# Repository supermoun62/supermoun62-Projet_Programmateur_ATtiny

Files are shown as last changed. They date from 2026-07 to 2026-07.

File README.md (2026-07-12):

Programmateur ATtiny 24/44/84 - 25/45/85 - 2313/4313 avec un Arduino Nano.
Vous pouvez récupérer le plan, tuo, liste matériel, fichiers Gerber.

https://github.com/supermoun62/supermoun62-Projet_Programmateur_ATtiny/blob/main/Github_Projet_Programmateur_ATtiny_V3_Images/Projet_Programmateur_ATtiny_V3_PCB.png

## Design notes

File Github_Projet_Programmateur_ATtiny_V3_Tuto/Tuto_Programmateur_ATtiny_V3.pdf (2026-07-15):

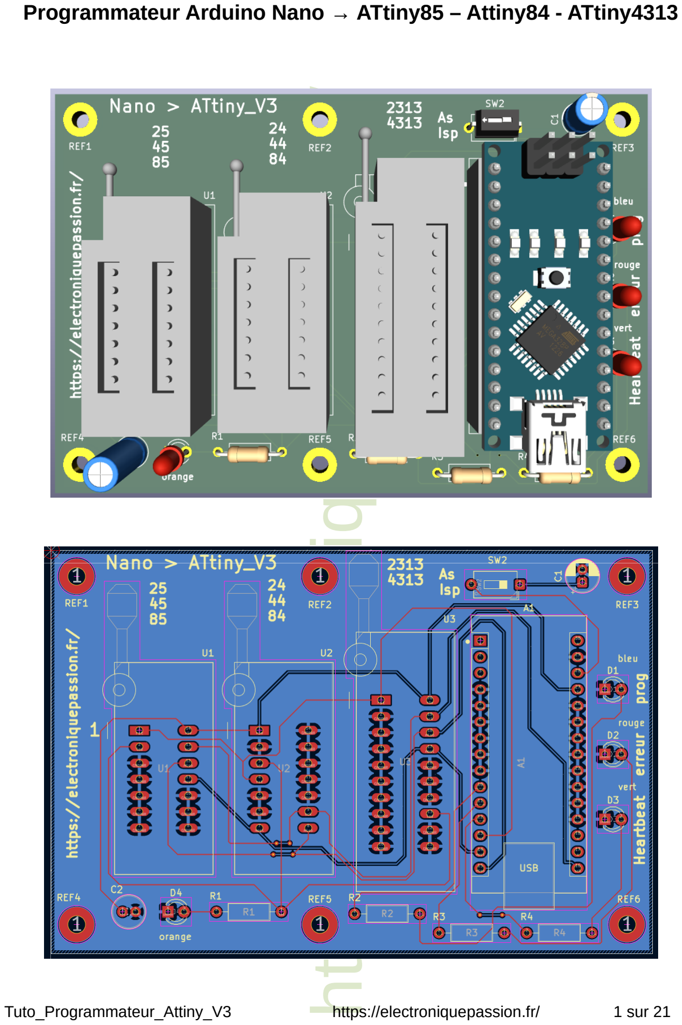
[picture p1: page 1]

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
Tuto_Programmateur_Attiny_V3 | https://electroniquepassion.fr/ | 1 sur 21

Programmateur Arduino Nano → ATtiny85 – Attiny84 - ATtiny4313

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
Tuto_Programmateur_Attiny_V3 | https://electroniquepassion.fr/ | 2 sur 21

Installation d’un Attiny 45, 85

Exemple : un Attiny 85
Insérez l’ATtiny sur le support zif. correspondant.
Pour le zif du 85, je vous conseille de coller un cache sur l’ensemble des pins non utilisées.
( Repérage des pins du zif : 5, 6, 7, 8, 9, 10 )

Informations pour récupérer le dossier Gerber, plans, liste matériel, STL
| à la fin du Tuto

Pour souder le Dip-Switch, ne pas oublier de le mettre dans le bon sens.

Contact fermé vers inscription AsIsp.

### Ce tuto a été réalisé avec un ArduinoIDE V 2.3.10

### Concernant les paramètres de la carte 2313 ou 4313, je n’ai

pas trouvé d’informations sur internet.

Ne pas oublier de mettre en paramètre clock interne.

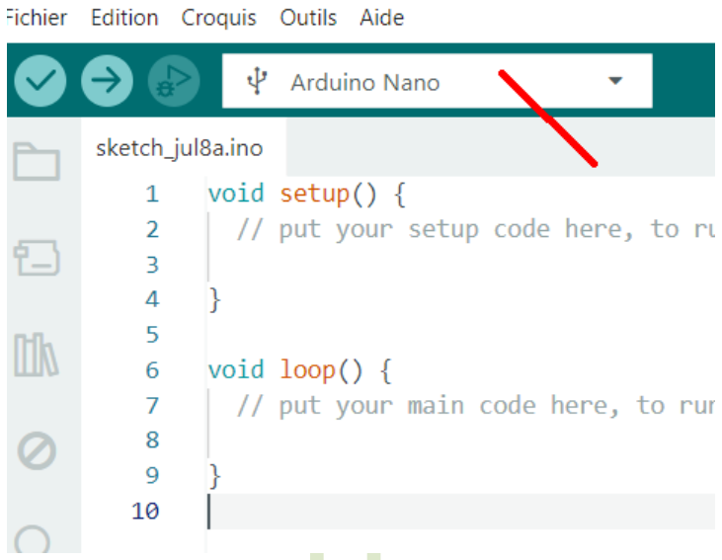
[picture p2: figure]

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
Préparation de l’Arduino Nano en module de programmation.

Arduino Nano

Choix du processeur !!!

Tuto_Programmateur_Attiny_V3 | https://electroniquepassion.fr/ | 3 sur 21

Positionner le Dip-Switch sur la droite afin d’avoir la capacité de 10uf non connectée.
Ensuite connectez le port USB

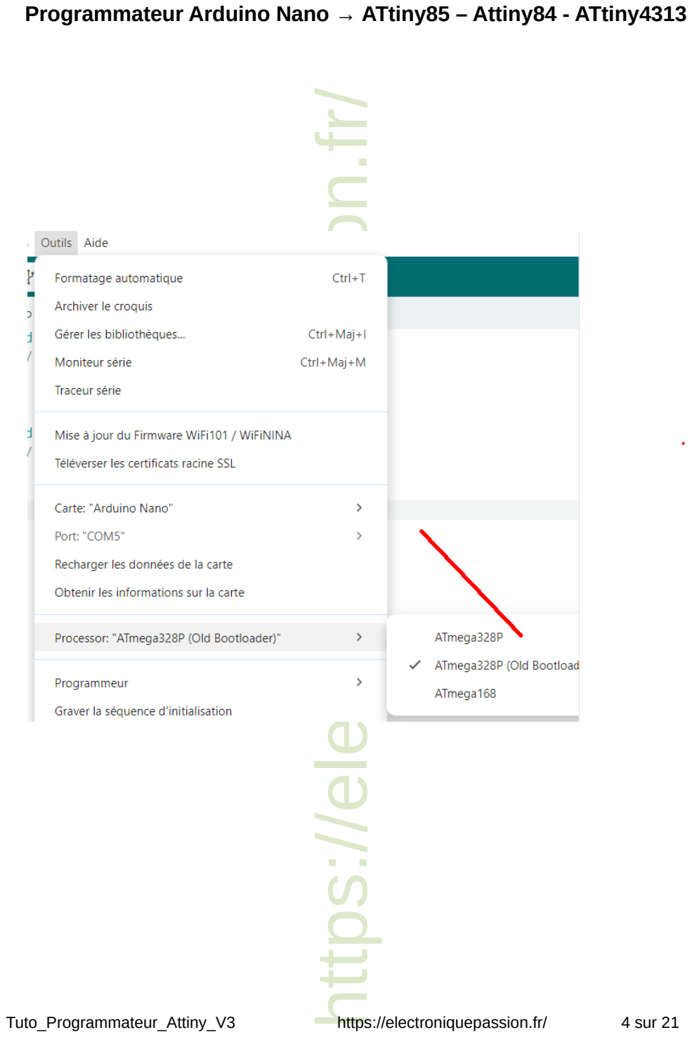
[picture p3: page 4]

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
Tuto_Programmateur_Attiny_V3 | https://electroniquepassion.fr/ | 4 sur 21

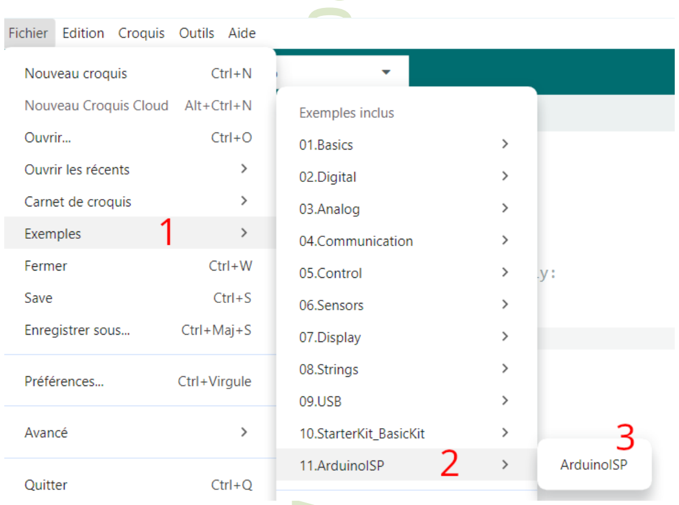
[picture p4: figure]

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
Ensuite ouvrir le croquis Arduino ISP de: Randall Bohn (https://github.com/rsbohn/arduinoisp)

Trouver le croquis : Exemples \ ArduinoISP

Téléverser le programme dans le Nano.

Vérifier l’absence de message de défaut.

A partir de ce moment la Nano est devenue programmateur d’ATtiny.

Tuto_Programmateur_Attiny_V3 | https://electroniquepassion.fr/ | 5 sur 21

Enlever le port USB, basculer le Dip-Switch sur la gauche afin de connecter la capacité de 10uf .
A partir de ce moment, ne plus toucher au Dip-Switch

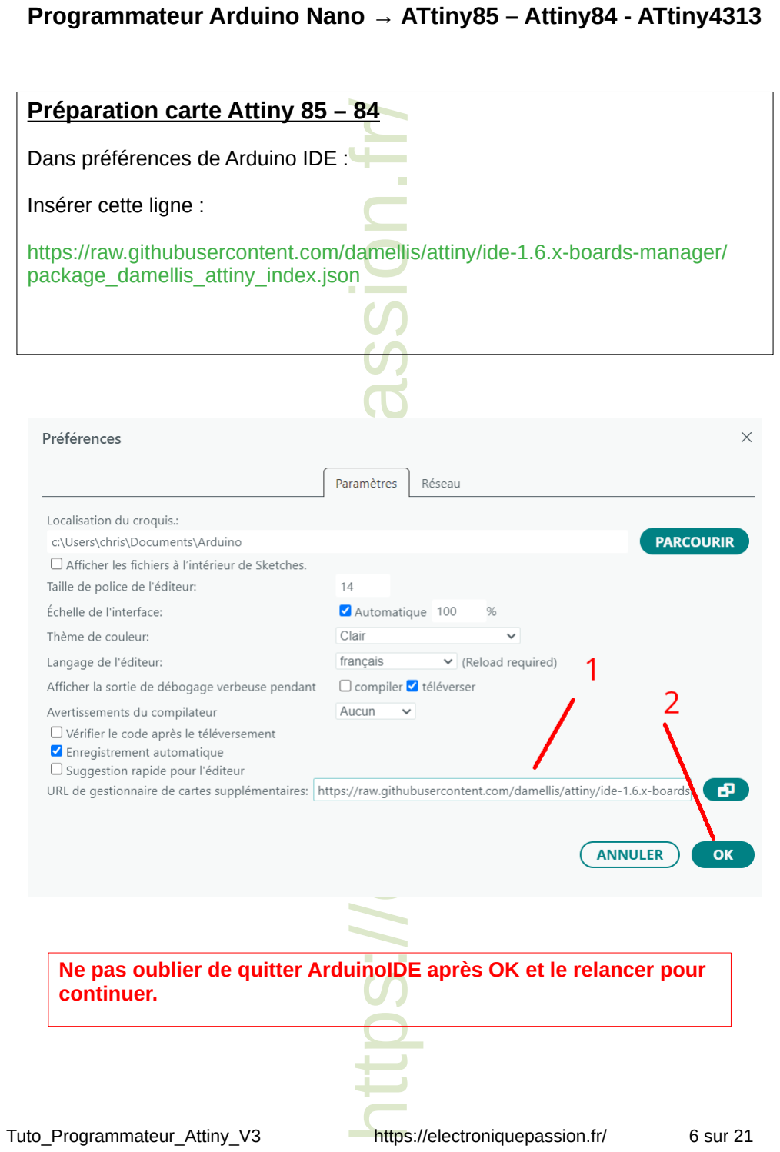
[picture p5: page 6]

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
Préparation carte Attiny 85 – 84

Dans préférences de Arduino IDE :

Insérer cette ligne :

https://raw.githubusercontent.com/damellis/attiny/ide-1.6.x-boards-manager/package_damellis_attiny_index.json

Ne pas oublier de quitter ArduinoIDE après OK et le relancer pour continuer.

Tuto_Programmateur_Attiny_V3 | https://electroniquepassion.fr/ | 6 sur 21

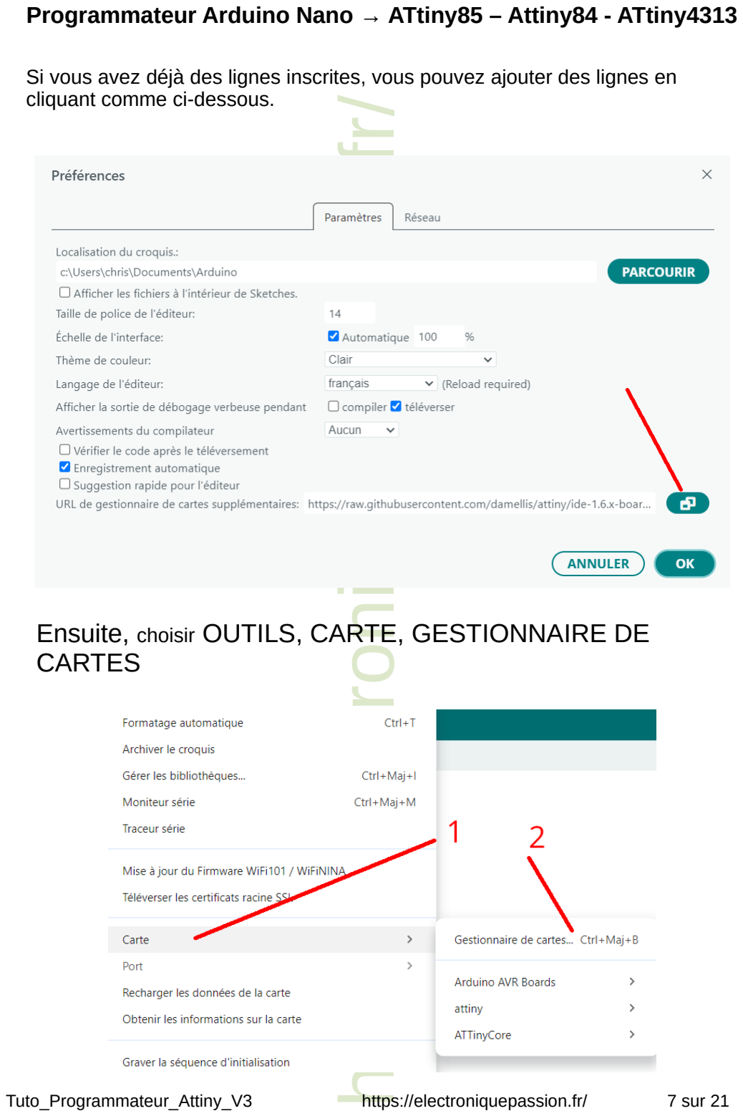
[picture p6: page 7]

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
Si vous avez déjà des lignes inscrites, vous pouvez ajouter des lignes en cliquant comme ci-dessous.

### Ensuite, choisir OUTILS, CARTE, GESTIONNAIRE DE CARTES

Tuto_Programmateur_Attiny_V3 | https://electroniquepassion.fr/ | 7 sur 21

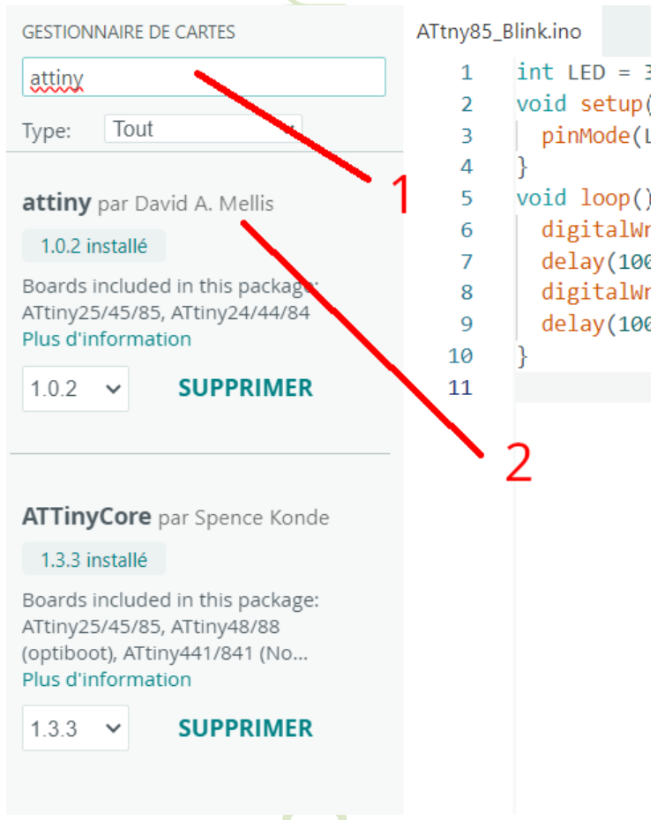
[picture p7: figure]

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
### Ensuite installer le gestionnaire de cartes de David A Mellis

Lorsque vous insérez ou enlevez un Attiny, faite-le cordon usb débranché.

Tuto_Programmateur_Attiny_V3 | https://electroniquepassion.fr/ | 8 sur 21

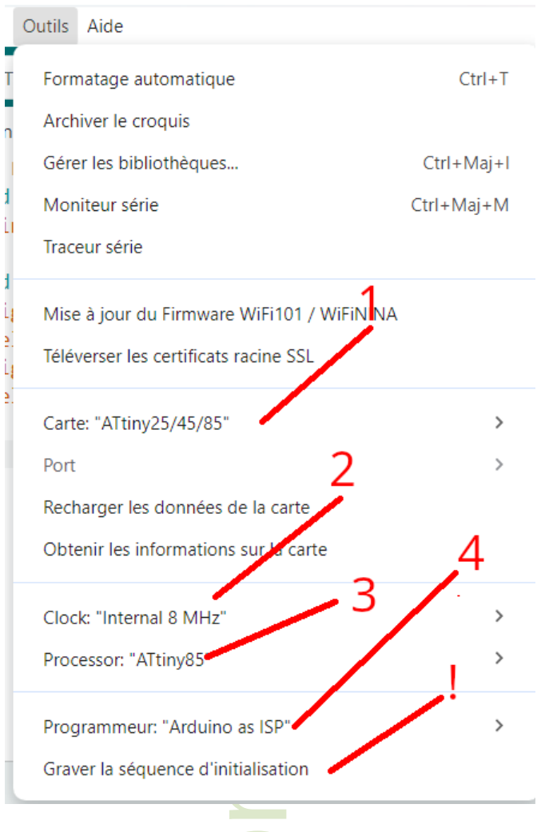
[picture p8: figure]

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
1) Choisir le type de carte
2) Choisir la fréquence. Attention mettre interne
3) Choisir le type Attiny. !!!!!
4) Choisir Arduino As Isp

Ne pas oublier de choisir le port. !!!!

Pour un Attiny neuf, graver la séquence d’initialisation avant de téléverser le programme
Téléverser le croquis ATtiny85

Après avoir téléverser le programme la diode orange doit clignoter. Vous pouvez modifier la fréquence d’allumage pour faire des essais de téléversement

Tuto_Programmateur_Attiny_V3 | https://electroniquepassion.fr/ | 9 sur 21

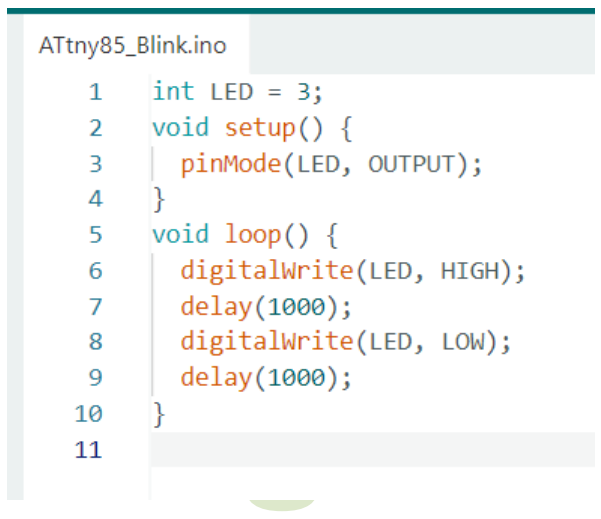
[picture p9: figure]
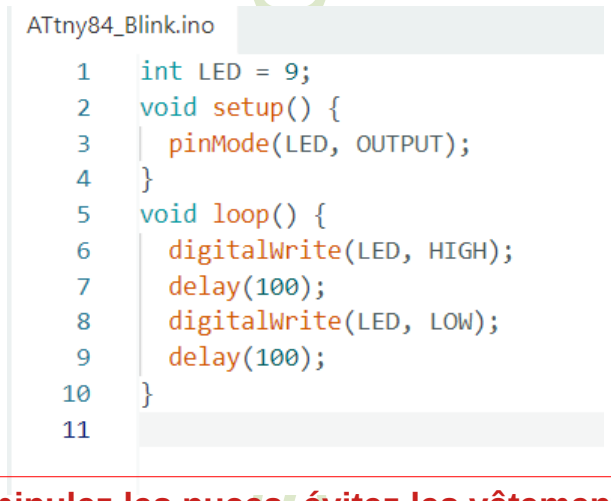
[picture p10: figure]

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
Lorsque vous insérez ou enlevez un Attiny, faite-le cordon usb débranché.

Croquis test ATtiny85

Croquis test ATtiny84

Lorsque vous manipulez les puces, évitez les vêtements qui peuvent provoquer de l’électricité statique.

Tuto_Programmateur_Attiny_V3 | https://electroniquepassion.fr/ | 10 sur 21

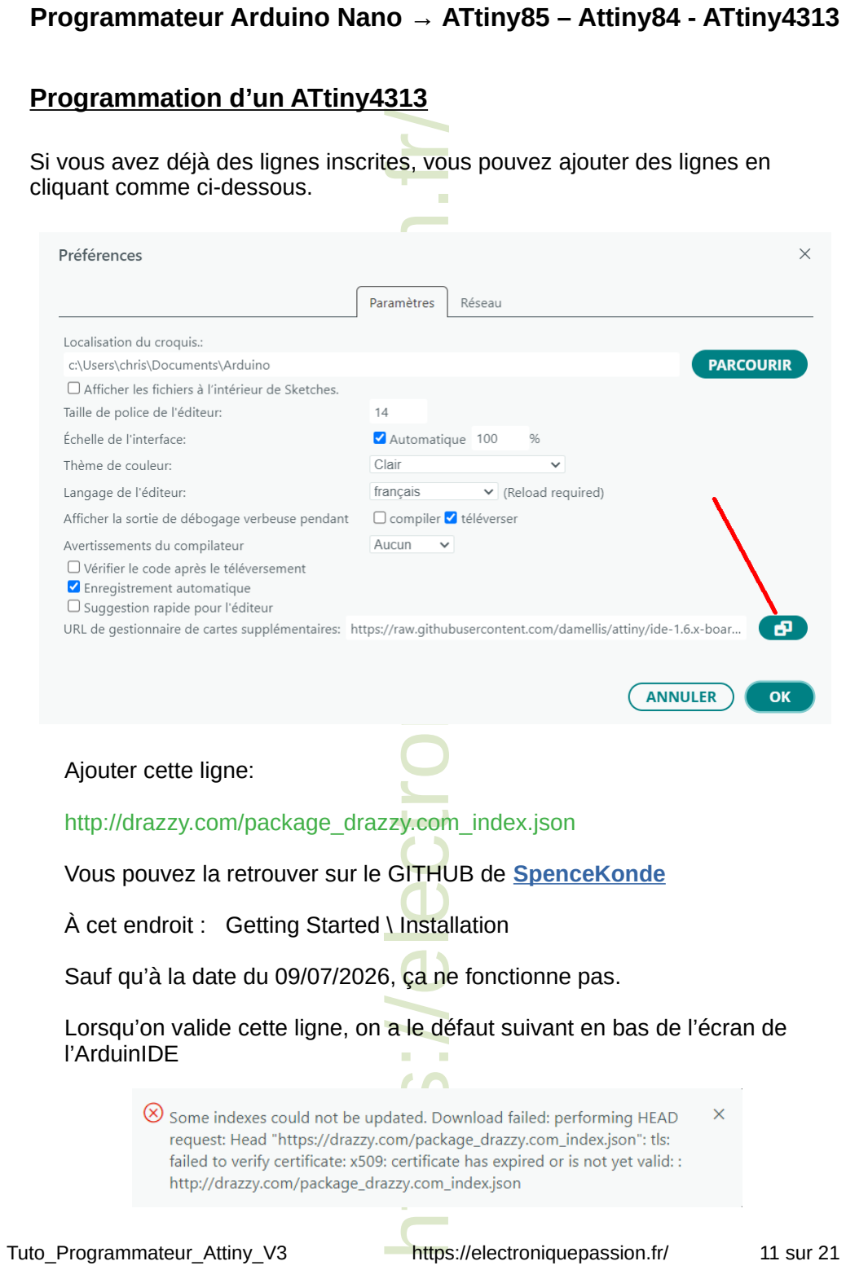
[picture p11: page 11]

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
Programmation d’un ATtiny4313

Si vous avez déjà des lignes inscrites, vous pouvez ajouter des lignes en cliquant comme ci-dessous.

Ajouter cette ligne:

http://drazzy.com/package_drazzy.com_index.json

Vous pouvez la retrouver sur le GITHUB de SpenceKonde (https://github.com/SpenceKonde/megaTinyCore)

À cet endroit : Getting Started \ Installation

Sauf qu’à la date du 09/07/2026, ça ne fonctionne pas.

Lorsqu’on valide cette ligne, on a le défaut suivant en bas de l’écran de l’ArduinIDE

Tuto_Programmateur_Attiny_V3 | https://electroniquepassion.fr/ | 11 sur 21

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
PS : Ne pas oublier d’effacer la ligne précédente avant d’insérer la ligne ci-dessus

A force de chercher sur la toile, j’ai trouvé cette ligne :

https://raw.githubusercontent.com/SpenceKonde/ReleaseScripts/refs/heads/master/package_drazzy.com_index.json

Sur le Forum Arduino CC (https://forum.arduino.cc/t/new-macbook-with-m4-chip-bad-cpu-in-executable/1422083/7)

Vous ne devez avoir aucun défaut en bas à droite.

Ca fonctionne aussi avec cette ligne:

https://descartes.net/package_drazzy.com_index.json

Tuto_Programmateur_Attiny_V3 | https://electroniquepassion.fr/ | 12 sur 21

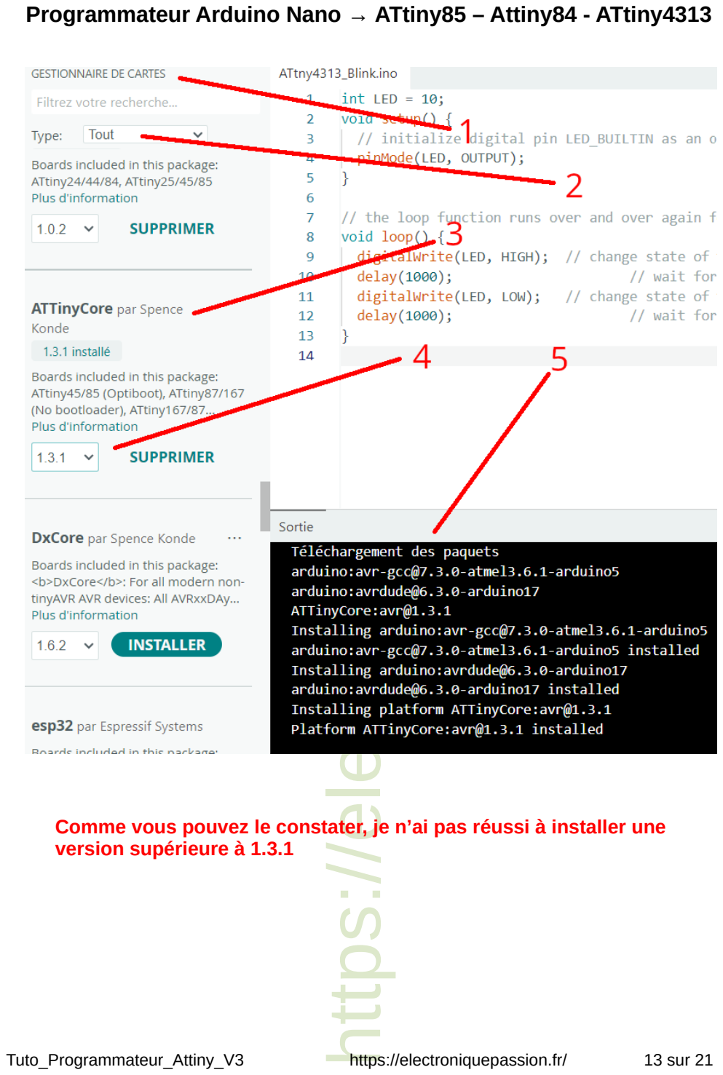
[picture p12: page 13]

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
Comme vous pouvez le constater, je n’ai pas réussi à installer une version supérieure à 1.3.1

Tuto_Programmateur_Attiny_V3 | https://electroniquepassion.fr/ | 13 sur 21

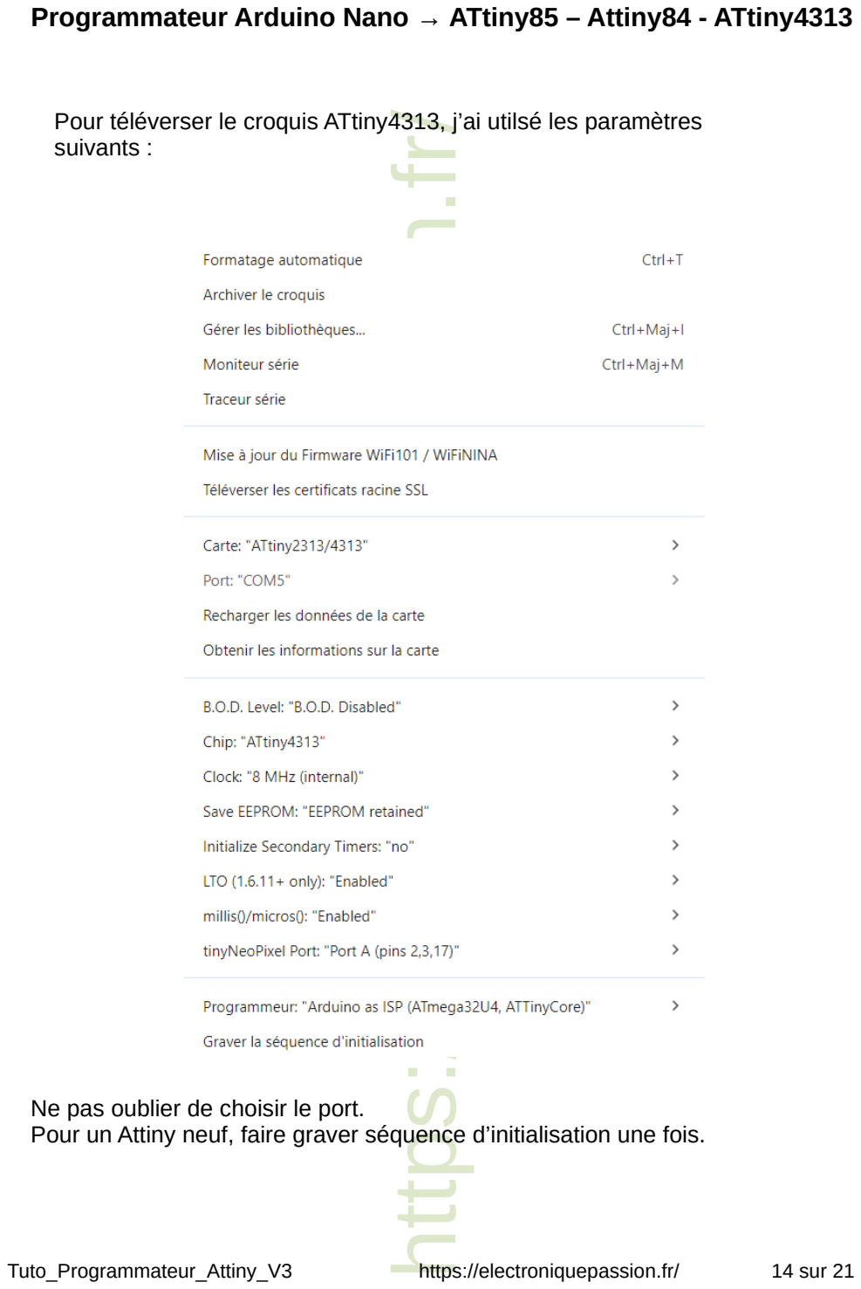
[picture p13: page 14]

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
Pour téléverser le croquis ATtiny4313, j’ai utilsé les paramètres suivants :

Ne pas oublier de choisir le port.
Pour un Attiny neuf, faire graver séquence d’initialisation une fois.
Tuto_Programmateur_Attiny_V3 | https://electroniquepassion.fr/ | 14 sur 21

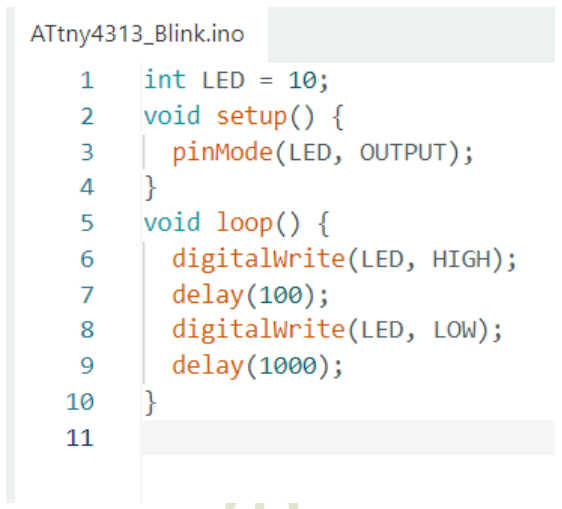
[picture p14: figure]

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
Croquis ATtiny4313

Tuto_Programmateur_Attiny_V3 | https://electroniquepassion.fr/ | 15 sur 21

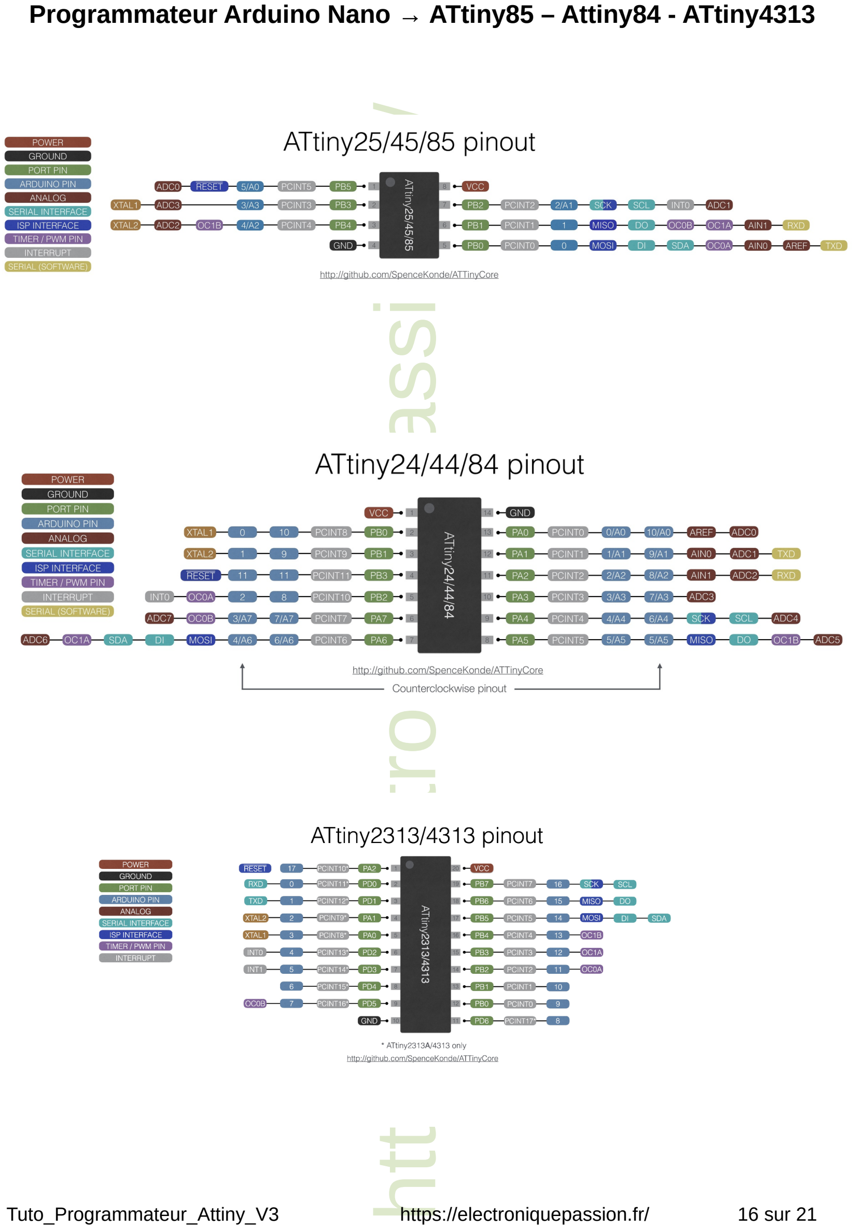
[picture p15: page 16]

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
Tuto_Programmateur_Attiny_V3 | https://electroniquepassion.fr/ | 16 sur 21

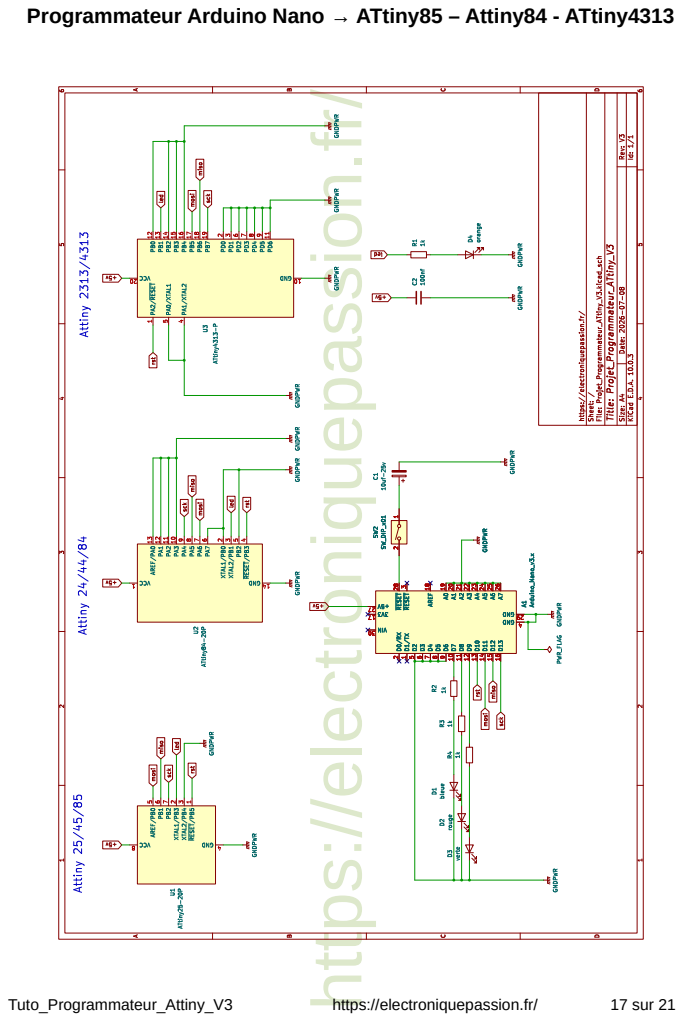
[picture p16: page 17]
Tuto_Programmateur_Attiny_V3; https://electroniquepassion.fr/; 17 sur 21

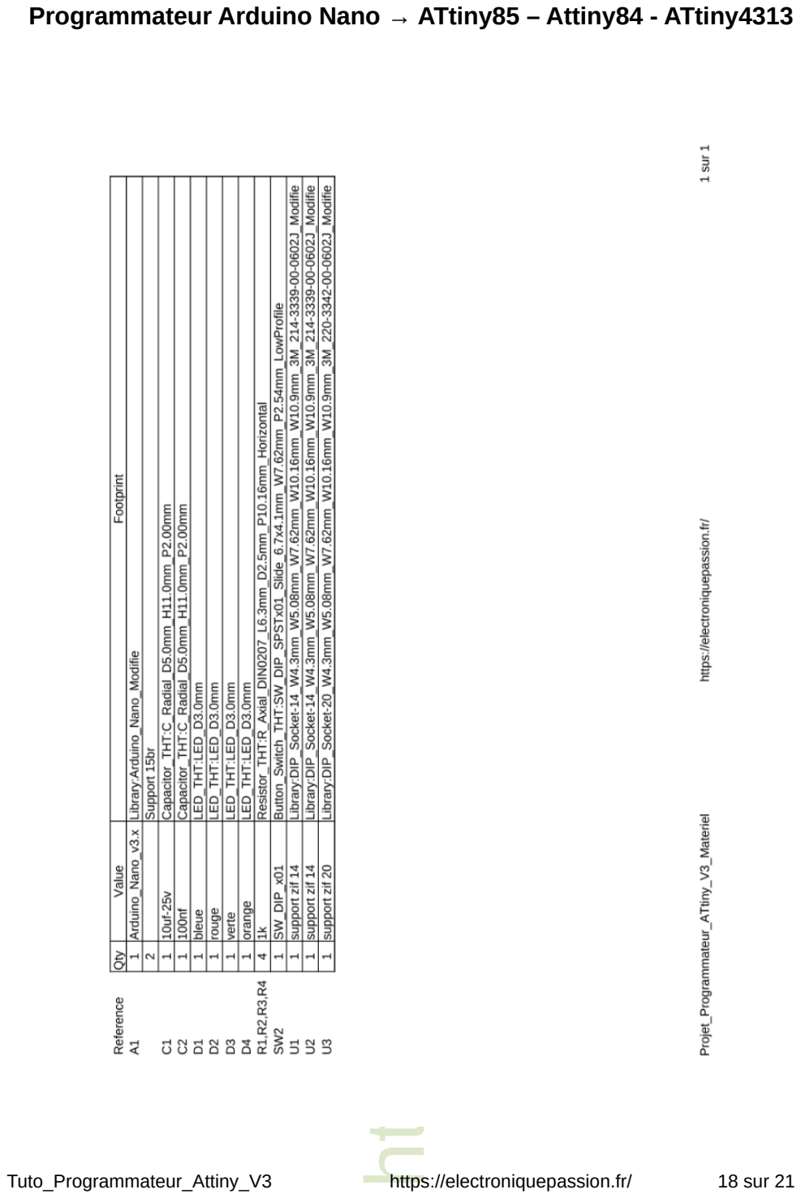
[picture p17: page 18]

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
Tuto_Programmateur_Attiny_V3 | https://electroniquepassion.fr/ | 18 sur 21

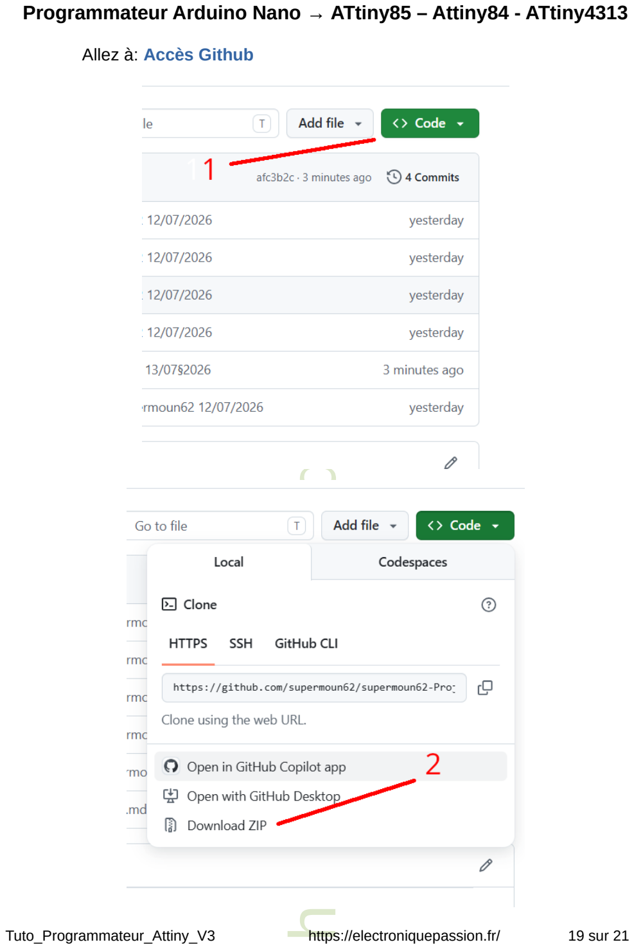
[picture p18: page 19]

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
Tuto_Programmateur_Attiny_V3 | https://electroniquepassion.fr/ | 19 sur 21

Allez à: Accès Github (https://github.com/supermoun62/supermoun62-Projet_Programmateur_ATtiny)

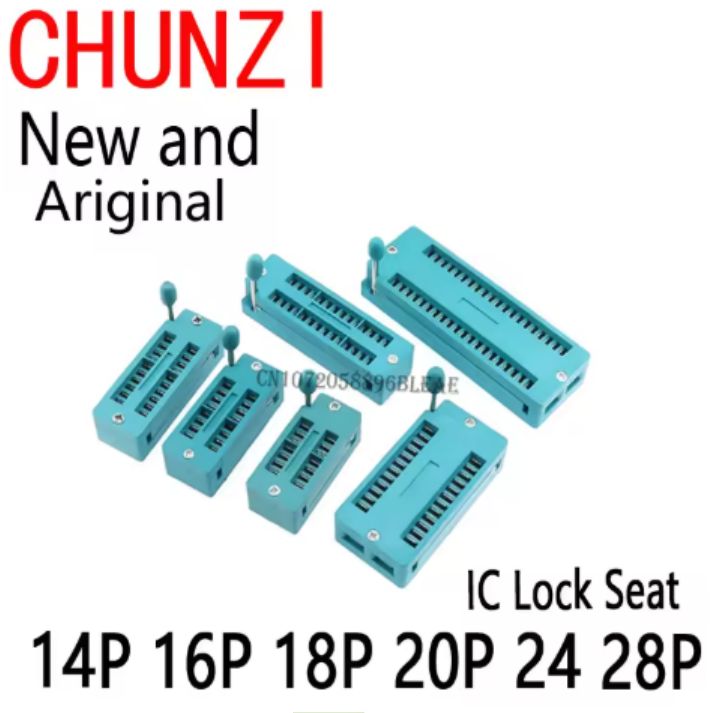
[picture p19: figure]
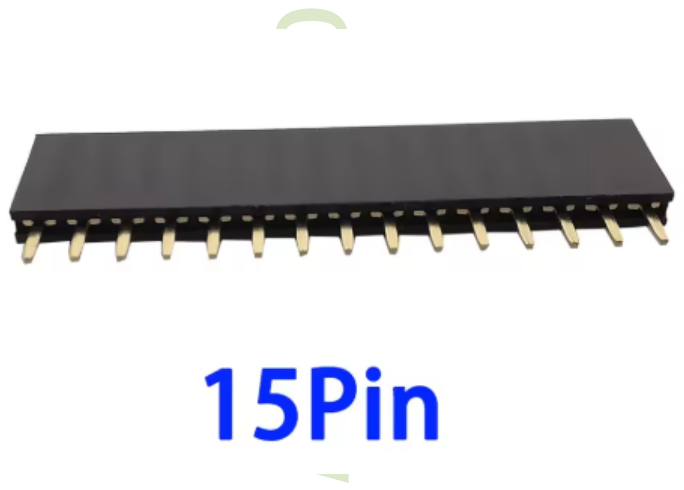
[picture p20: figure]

t

t

# p (https://fr.aliexpress.com/item/1005008298604978.html?curPageLogUid=roLoERoopyk8)

s

:

n

i

# q (https://fr.aliexpress.com/item/1005011780751558.html)

u

Tuto_Programmateur_Attiny_V3 | https://electroniquepassion.fr/ | 20 sur 21

### AliExpress (https://fr.aliexpress.com/item/1005011780751558.html)

AliExpress (https://fr.aliexpress.com/item/1005008298604978.html?curPageLogUid=roLoERoopyk8)

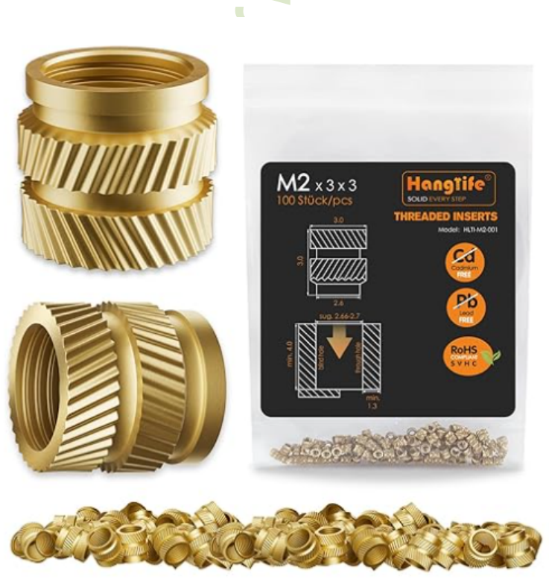
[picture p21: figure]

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
# n (https://amzn.eu/d/08rn6Pj5)

i

/

Tuto_Programmateur_Attiny_V3 | https://electroniquepassion.fr/ | 21 sur 21

### Amazon (https://amzn.eu/d/08rn6Pj5)

Pour le coffret en PLA, j’ai utisé les inserts suivants :

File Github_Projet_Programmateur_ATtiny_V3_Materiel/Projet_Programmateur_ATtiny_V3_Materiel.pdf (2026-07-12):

Projet_Programmateur_ATtiny_V3_Materiel | https://electroniquepassion.fr/ | 1 sur 1
Reference | Qty | Value | Footprint
A1 | 1 | Arduino_Nano_v3.x | Library:Arduino_Nano_Modifie
| 2 | | Support 15br
C1 | 1 | 10uf-25v | Capacitor_THT:C_Radial_D5.0mm_H11.0mm_P2.00mm
C2 | 1 | 100nf | Capacitor_THT:C_Radial_D5.0mm_H11.0mm_P2.00mm
D1 | 1 | bleue | LED_THT:LED_D3.0mm
D2 | 1 | rouge | LED_THT:LED_D3.0mm
D3 | 1 | verte | LED_THT:LED_D3.0mm
D4 | 1 | orange | LED_THT:LED_D3.0mm
R1,R2,R3,R4 | 4 | 1k | Resistor_THT:R_Axial_DIN0207_L6.3mm_D2.5mm_P10.16mm_Horizontal
SW2 | 1 | SW_DIP_x01 | Button_Switch_THT:SW_DIP_SPSTx01_Slide_6.7x4.1mm_W7.62mm_P2.54mm_LowProfile
U1 | 1 | support zif 14 | Library:DIP_Socket-14_W4.3mm_W5.08mm_W7.62mm_W10.16mm_W10.9mm_3M_214-3339-00-0602J_Modifie
U2 | 1 | support zif 14 | Library:DIP_Socket-14_W4.3mm_W5.08mm_W7.62mm_W10.16mm_W10.9mm_3M_214-3339-00-0602J_Modifie
U3 | 1 | support zif 20 | Library:DIP_Socket-20_W4.3mm_W5.08mm_W7.62mm_W10.16mm_W10.9mm_3M_220-3342-00-0602J_Modifie

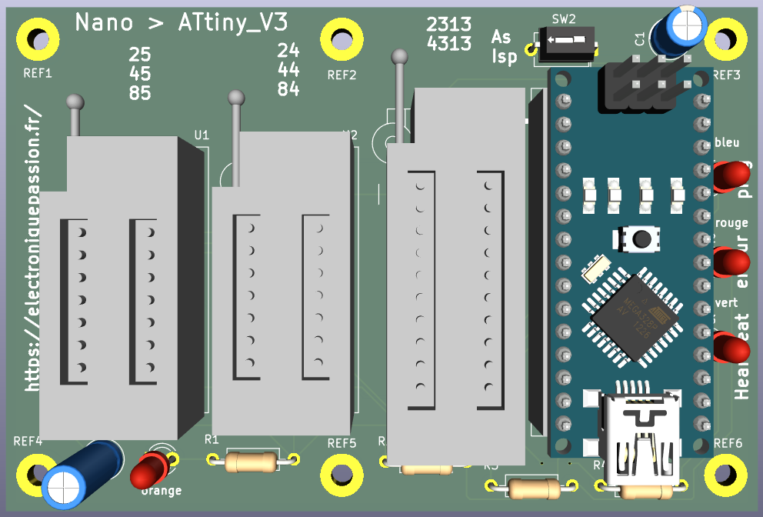
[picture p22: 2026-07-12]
Github_Projet_Programmateur_ATtiny_V3_Images/Projet_Programmateur_ATtiny_V3_PCB.png

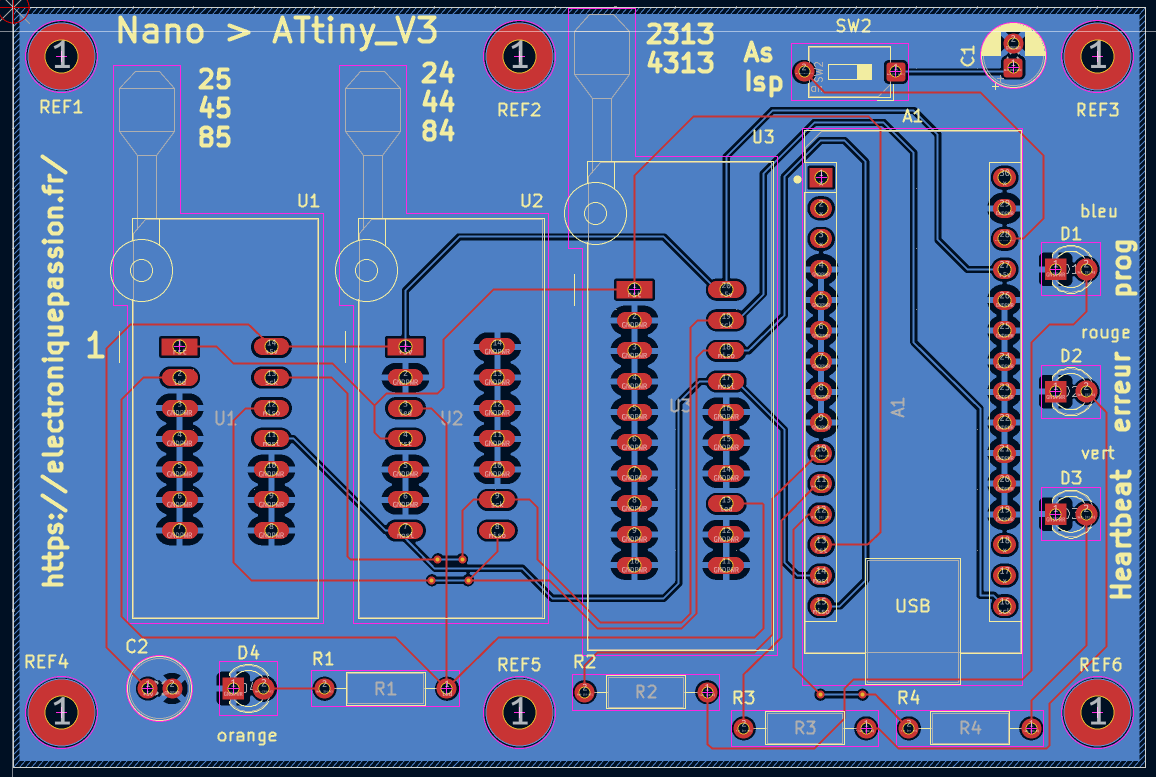
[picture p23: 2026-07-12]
Github_Projet_Programmateur_ATtiny_V3_Images/Projet_Programmateur_ATtiny_V3_Trace_PCB.png

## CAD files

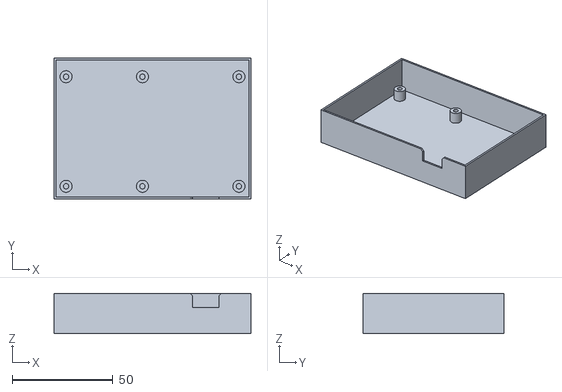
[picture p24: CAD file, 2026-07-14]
Github_Programmateur_ATtiny_V3_STL/Projet_Programmateur_ATtiny_Coffret.stl
98.0 x 70.0 x 20.0

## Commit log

2026-07-12 1er commit supermoun62 12/07/2026
    [Projet_Programmateur_ATtiny_V3-B_Cu.gbr, Projet_Programmateur_ATtiny_V3-B_Mask.gbr, Projet_Programmateur_ATtiny_V3-B_Paste.gbr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]
2026-07-14 Ajout fichiers STL supermoun62 14/07§2026
    [Projet_Programmateur_ATtiny_Coffret.stl]
2026-07-14 Mise à jour fichier gerber supermoun62 14/07/2026
